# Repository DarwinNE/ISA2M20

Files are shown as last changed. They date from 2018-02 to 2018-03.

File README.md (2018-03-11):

# ISA2M20
Adapter for 8-bit ISA card for the Olivetti M20

This project is dedicated to an adapter that allows to connect 8 bit ISA boards to
the bus of an Olivetti M20. Yes, we are talking about 1982 technology.
That may allow to do some nice stuff on the M20 as long as you are able to write the
software for the cards you want to attach.

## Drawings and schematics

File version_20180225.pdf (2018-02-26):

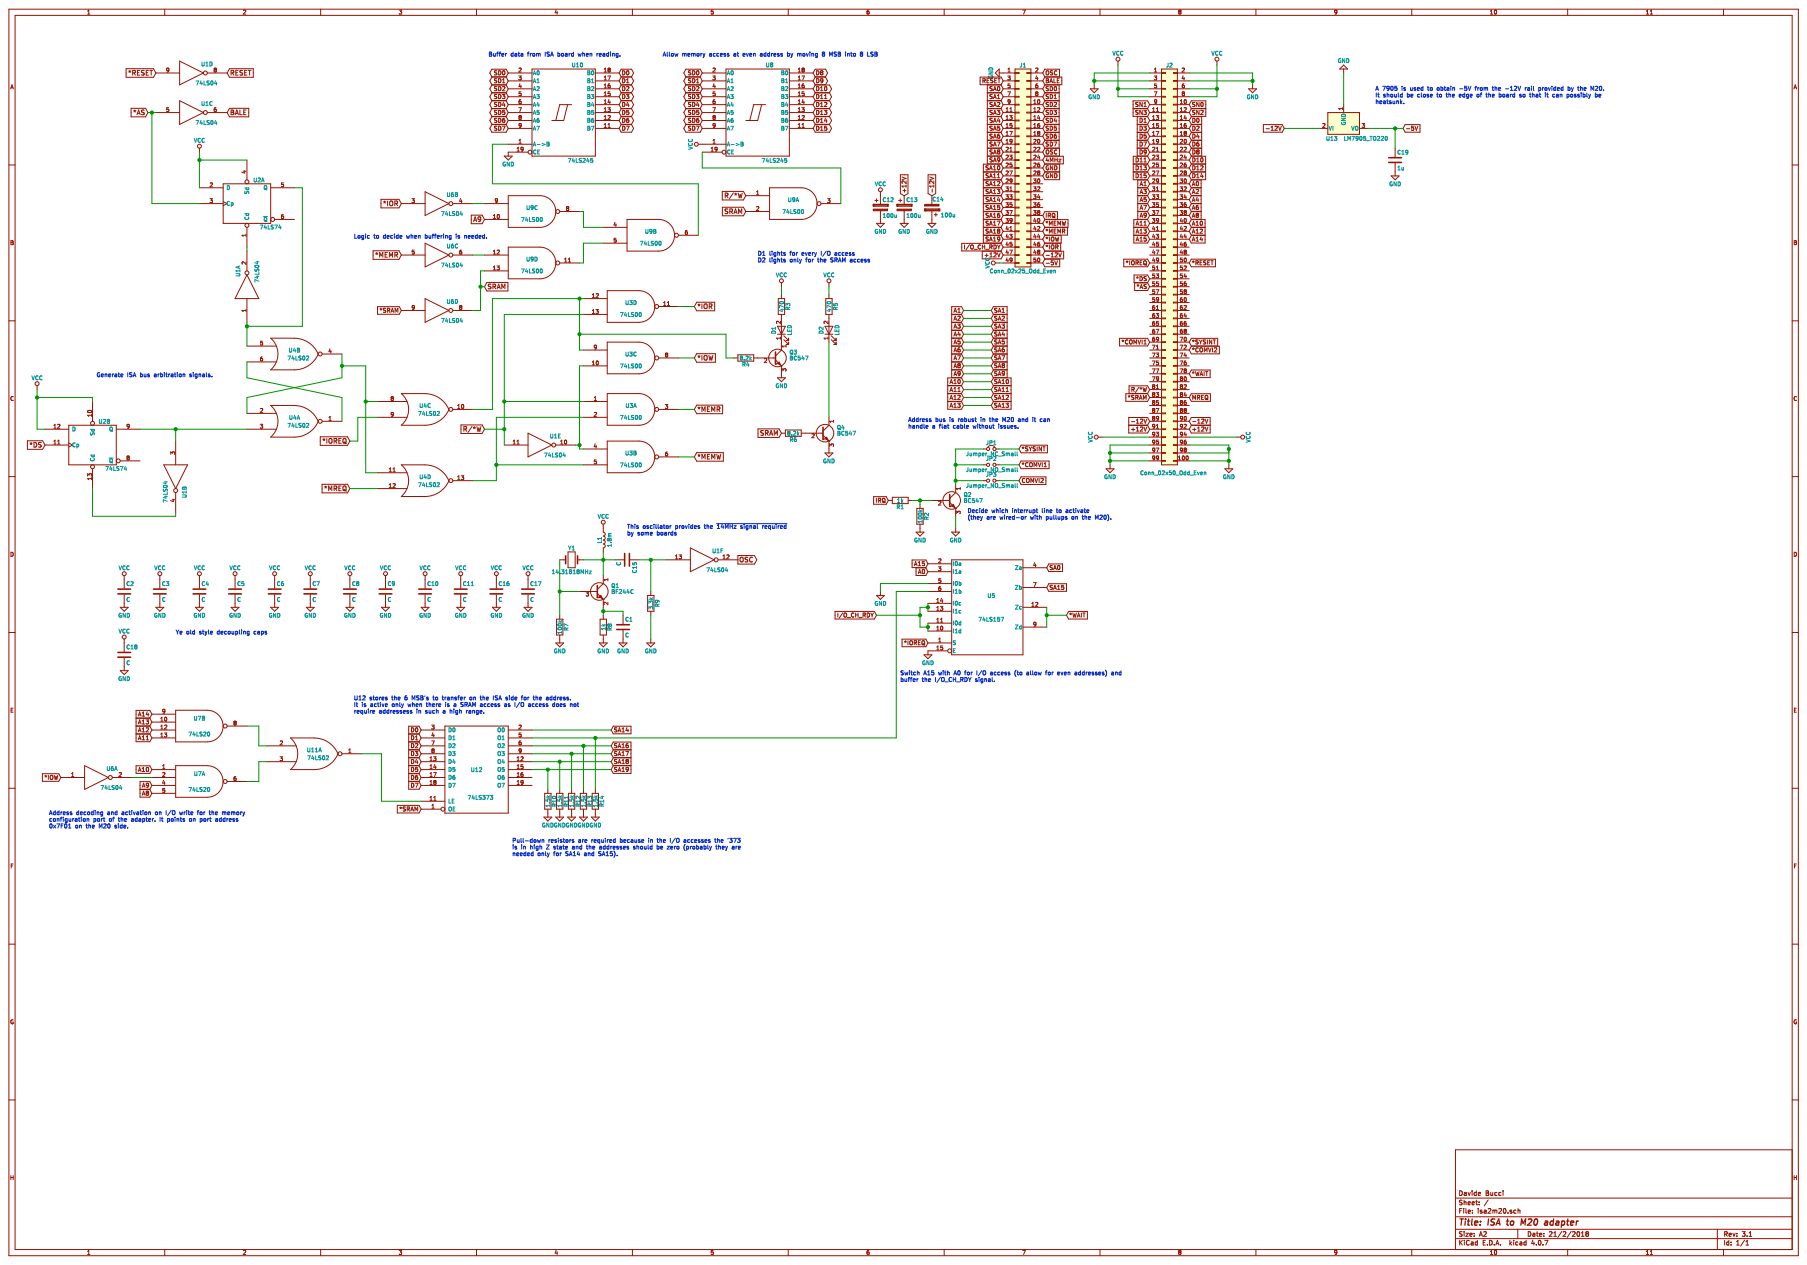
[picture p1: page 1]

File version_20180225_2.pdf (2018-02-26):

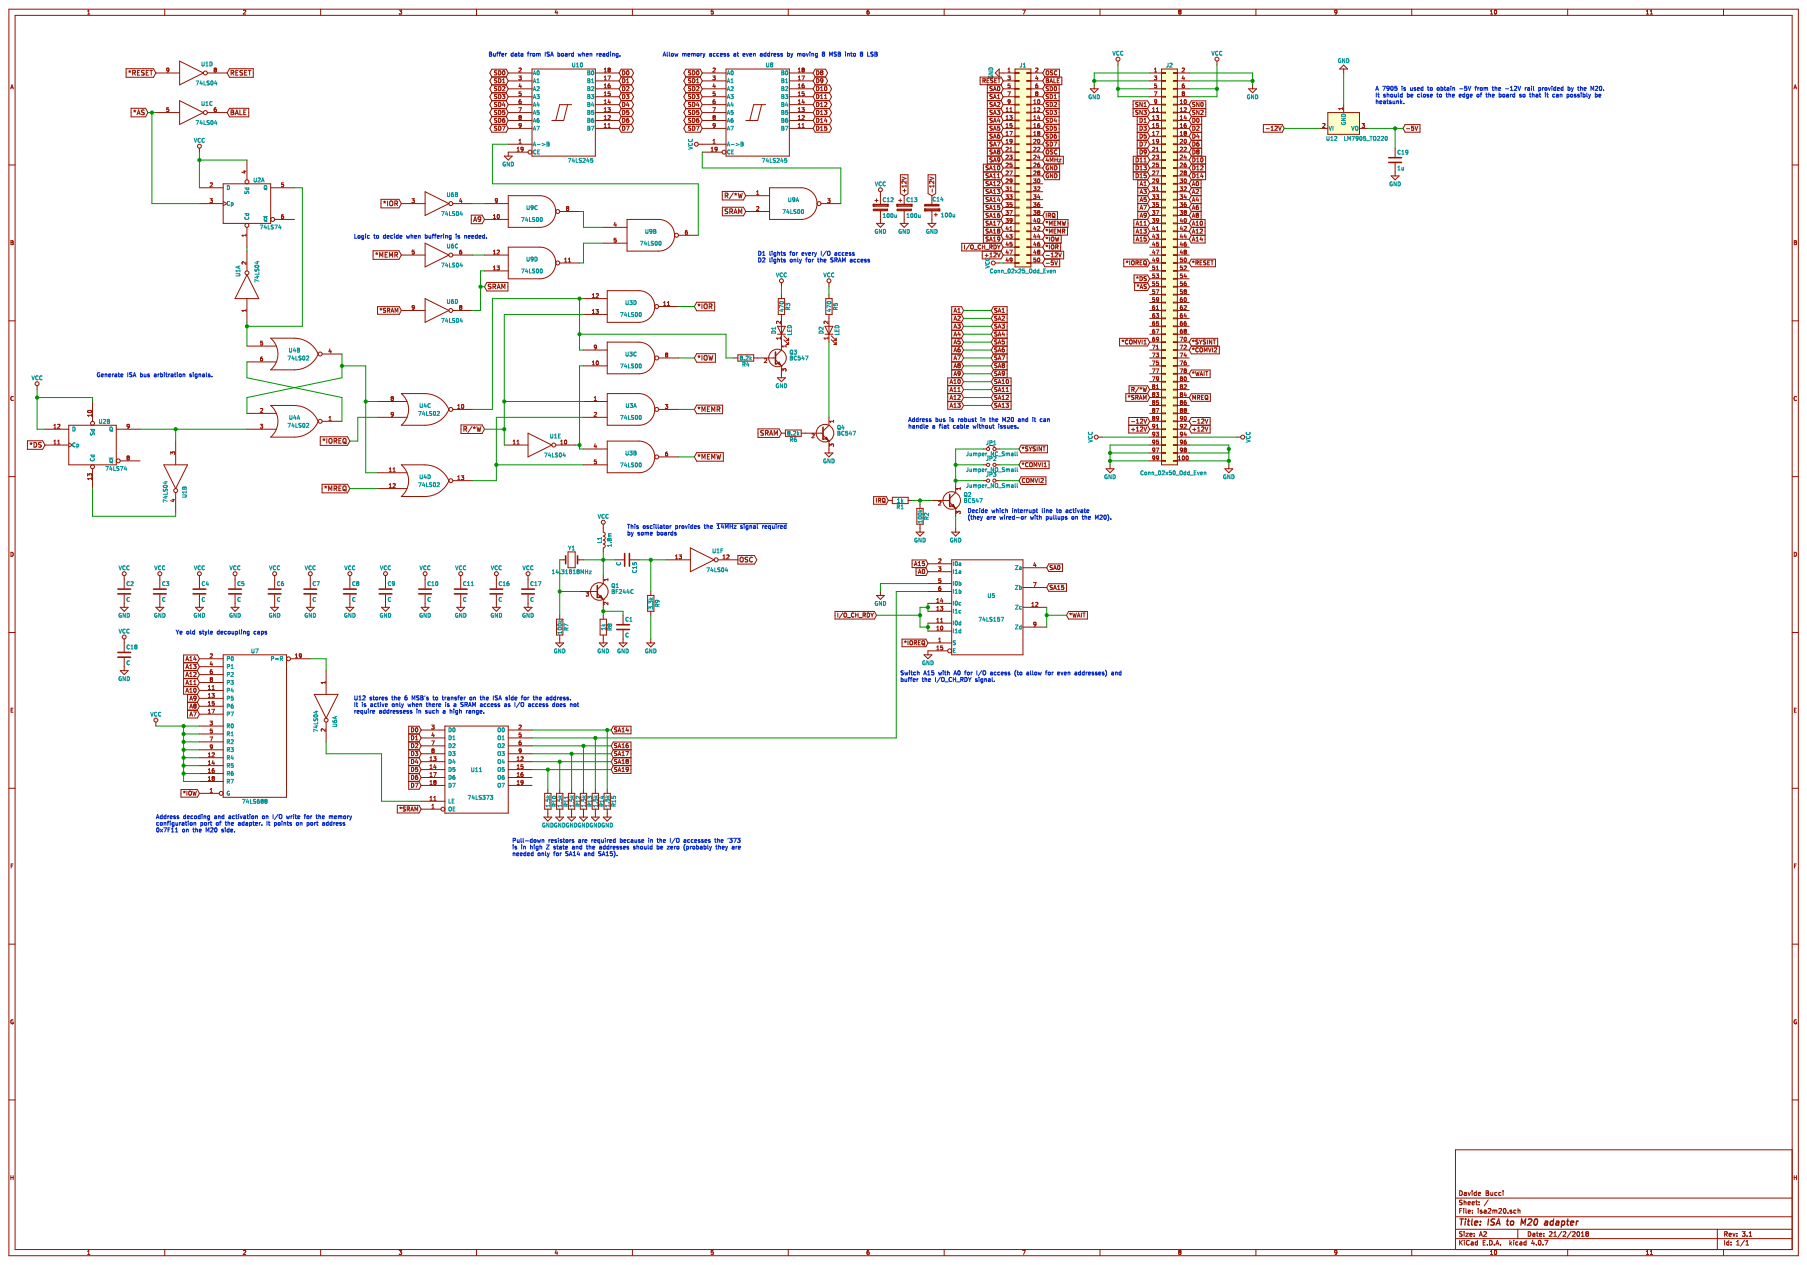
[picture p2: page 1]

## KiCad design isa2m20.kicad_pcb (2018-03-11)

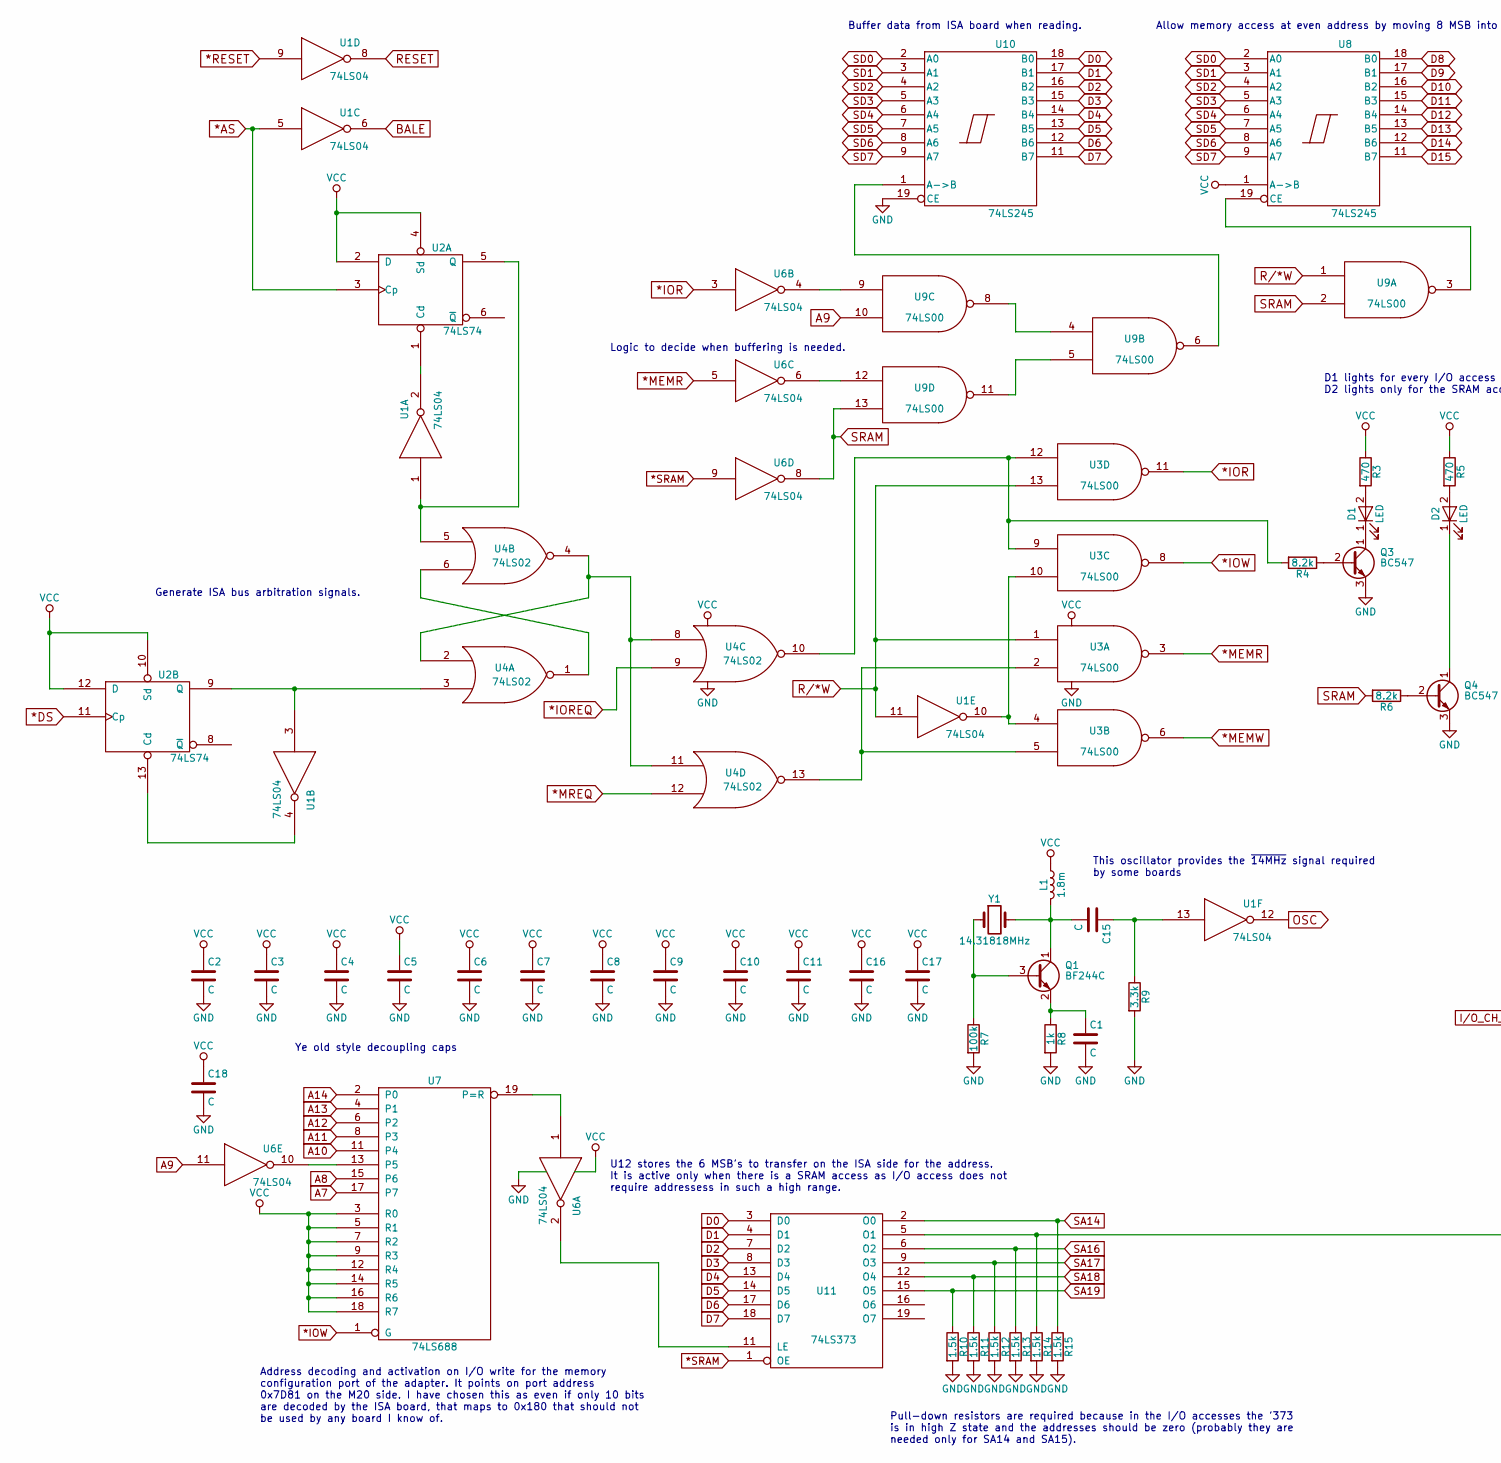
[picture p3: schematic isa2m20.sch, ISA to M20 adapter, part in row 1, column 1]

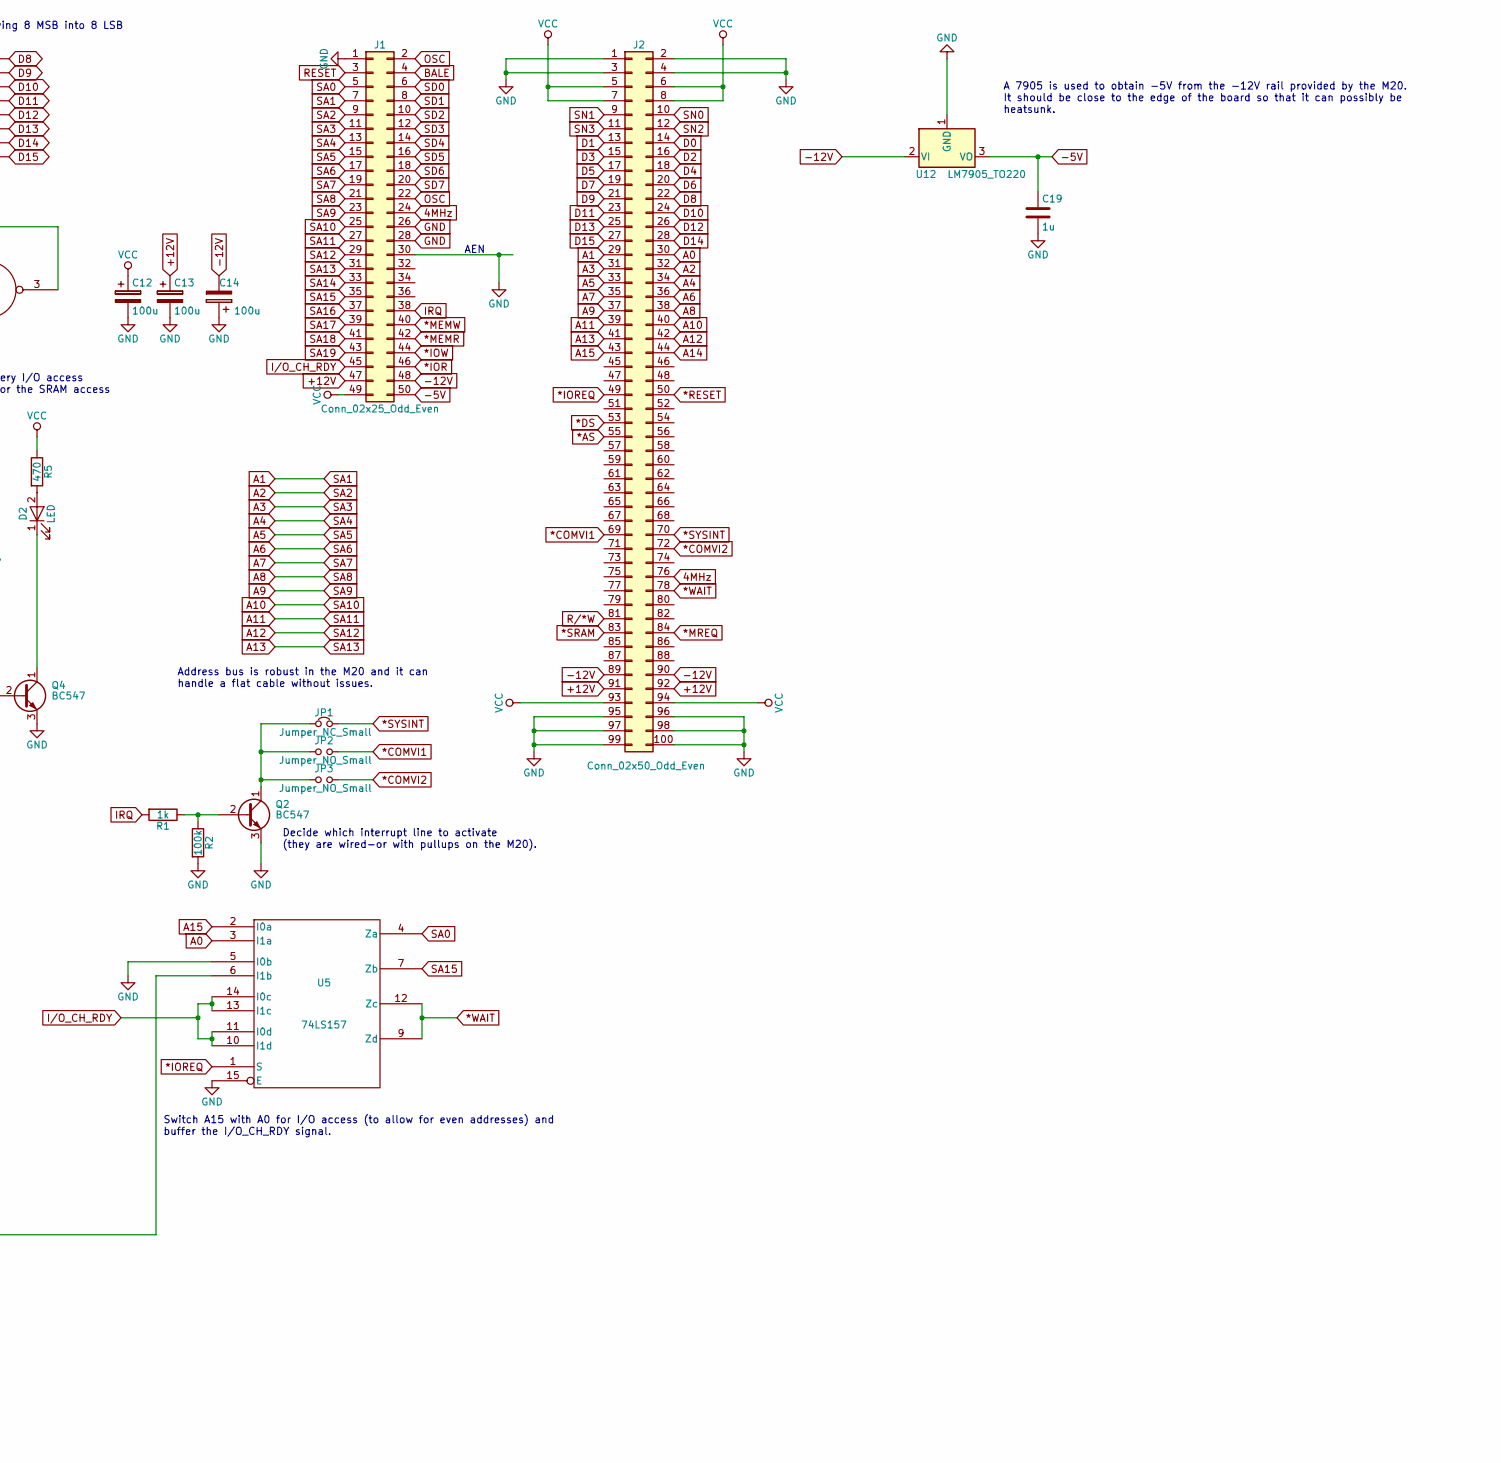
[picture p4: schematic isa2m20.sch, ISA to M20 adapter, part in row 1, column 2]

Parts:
C1: C; C_Axial_L5.1mm_D3.1mm_P7.50mm_Horizontal
C2, C3, C4, C5, C6, C7, C8, C9, C10, C11, C15, C16, C17, C18: C; C_Rect_L9.0mm_W2.5mm_P7.50mm_MKT
C12, C13, C14: 100u; CP_Radial_D10.0mm_P5.00mm
C19: 1u; C_Rect_L9.0mm_W2.5mm_P7.50mm_MKT
D1, D2: LED; LED_D3.0mm
J1: Conn_02x25_Odd_Even; Multicomp_MC9A12-5034_2x25x2.54mm_Straight
J2: Conn_02x50_Odd_Even; 2x50pin_PCB_edge_connector
JP1: Jumper_NC_Small; Socket_Strip_Straight_1x02_Pitch2.54mm
JP2, JP3: Jumper_NO_Small; Socket_Strip_Straight_1x02_Pitch2.54mm
L1: 1.8m; L_Radial_D7.5mm_P5.00mm_Fastron_07P
Q1: BF244C; TO-92_Molded_Narrow
Q2, Q3, Q4: BC547; TO-92_Molded_Narrow
R1, R8: 1k; R_Axial_DIN0207_L6.3mm_D2.5mm_P7.62mm_Horizontal
R2, R7: 100k; R_Axial_DIN0207_L6.3mm_D2.5mm_P7.62mm_Horizontal
R3, R5: 470; R_Axial_DIN0207_L6.3mm_D2.5mm_P7.62mm_Horizontal
R4, R6: 8.2k; R_Axial_DIN0207_L6.3mm_D2.5mm_P7.62mm_Horizontal
R9: 3.3k; R_Axial_DIN0207_L6.3mm_D2.5mm_P7.62mm_Horizontal
R10, R11, R12, R13, R14, R15: 1.5k; R_Axial_DIN0207_L6.3mm_D2.5mm_P7.62mm_Horizontal
U1, U6: 74LS04; DIP-14_W7.62mm_Socket_LongPads
U2: 74LS74; DIP-14_W7.62mm_Socket_LongPads
U3, U9: 74LS00; DIP-14_W7.62mm_Socket_LongPads
U4: 74LS02; DIP-14_W7.62mm_Socket_LongPads
U5: 74LS157; DIP-16_W7.62mm_Socket_LongPads
U7: 74LS688; DIP-20_W7.62mm_Socket_LongPads
U8, U10: 74LS245; DIP-20_W7.62mm_Socket_LongPads
U11: 74LS373; DIP-20_W7.62mm_Socket_LongPads
U12: LM7905_TO220; TO-220-3_Vertical
Y1: 14.31818MHz; Crystal_HC18-U_Vertical

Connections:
4MHz: J1.24, J2.76
*AS: J2.55, U1.5, U2.3 (Cp)
*COMVI1: J2.69, JP2.2
*COMVI2: J2.72, JP3.2
*DS: J2.53, U2.11 (Cp)
*IOR: J1.46, U3.11, U6.3
*IOREQ: J2.49, U4.9, U5.1 (S)
*IOW: J1.44, U3.8, U7.1 (G)
*MEMR: J1.42, U3.3, U6.5
*MEMW: J1.40, U3.6
*MREQ: J2.84, U4.12
*RESET: J2.50, U1.9
*SRAM: J2.83, U6.9, U11.1 (OE)
*SYSINT: J2.70, JP1.2
*WAIT: J2.78, U5.9 (Zd), U5.12 (Zc)
+12V: C13.1, J1.47, J2.91, J2.92
-5V: C19.1, J1.50, U12.3 (VO)
-12V: C14.2, J1.48, J2.89, J2.90, U12.2 (VI)
A0: J2.30, U5.3 (I1a)
A1: J1.7, J2.29
A2: J1.9, J2.32
A3: J1.11, J2.31
A4: J1.13, J2.34
A5: J1.15, J2.33
A6: J1.17, J2.36
A7: J1.19, J2.35, U7.17 (P7)
A8: J1.21, J2.38, U7.15 (P6)
A9: J1.23, J2.37, U6.11, U9.10
A10: J1.25, J2.40, U7.11 (P4)
A11: J1.27, J2.39, U7.8 (P3)
A12: J1.29, J2.42, U7.6 (P2)
A13: J1.31, J2.41, U7.4 (P1)
A14: J2.44, U7.2 (P0)
A15: J2.43, U5.2 (I0a)
BALE: J1.4, U1.6
D0: J2.14, U10.18 (B0), U11.3 (D0)
D1: J2.13, U10.17 (B1), U11.4 (D1)
D2: J2.16, U10.16 (B2), U11.7 (D2)
D3: J2.15, U10.15 (B3), U11.8 (D3)
D4: J2.18, U10.14 (B4), U11.13 (D4)
D5: J2.17, U10.13 (B5), U11.14 (D5)
D6: J2.20, U10.12 (B6), U11.17 (D6)
D7: J2.19, U10.11 (B7), U11.18 (D7)
D8: J2.22, U8.18 (B0)
D9: J2.21, U8.17 (B1)
D10: J2.24, U8.16 (B2)
D11: J2.23, U8.15 (B3)
D12: J2.26, U8.14 (B4)
D13: J2.25, U8.13 (B5)
D14: J2.28, U8.12 (B6)
D15: J2.27, U8.11 (B7)
GND: C1.2, C2.2, C3.2, C4.2, C5.2, C6.2, C7.2, C8.2, C9.2, C10.2, C11.2, C12.2, C13.2, C14.1, C16.2, C17.2, C18.2, C19.2, J1.1, J1.26, J1.28, J1.30, J2.1, J2.2, J2.3, J2.4, J2.95, J2.96, J2.97, J2.98, J2.99, J2.100, Q2.3 (E), Q3.3 (E), Q4.3 (E), R2.2, R7.2, R8.2, R9.2, R10.2, R11.2, R12.2, R13.2, R14.2, R15.2, U1.7 (GND), U2.7 (GND), U3.7 (GND), U4.7 (GND), U5.5 (I0b), U5.8 (GND), U5.15 (E), U6.7 (GND), U7.10 (GND), U8.10 (GND), U9.7 (GND), U10.10 (GND), U10.19 (CE), U11.10 (GND), U12.1 (GND)
I/O_CH_RDY: J1.45, U5.10 (I1d), U5.11 (I0d), U5.13 (I1c), U5.14 (I0c)
IRQ: J1.38, R1.2
unnamed: C1.1, Q1.2 (E), R8.1
unnamed: C15.1, R9.1, U1.13
unnamed: C15.2, L1.2, Q1.1 (C), Y1.2
unnamed: D1.1 (K), Q3.1 (C)
unnamed: D1.2 (A), R3.2
unnamed: D2.1 (K), Q4.1 (C)
unnamed: D2.2 (A), R5.2
unnamed: JP1.1, JP2.1, JP3.1, Q2.1 (C)
unnamed: Q1.3 (B), R7.1, Y1.1
unnamed: Q2.2 (B), R1.1, R2.1
unnamed: Q3.2 (B), R4.1
unnamed: Q4.2 (B), R6.1
unnamed: R4.2, U3.9, U3.12, U4.10
unnamed: R14.1, U5.6 (I1b), U11.5 (O1)
unnamed: U1.1, U2.5 (Q), U4.5
unnamed: U1.2, U2.1 (Cd)
unnamed: U1.3, U2.9 (Q), U4.3
unnamed: U1.4, U2.13 (Cd)
unnamed: U1.10, U3.4, U3.10
unnamed: U3.2, U3.5, U4.13
unnamed: U4.1, U4.6
unnamed: U4.2, U4.4, U4.8, U4.11
unnamed: U6.1, U7.19 (P=R)
unnamed: U6.4, U9.9
unnamed: U6.6, U9.12
unnamed: U6.10, U7.13 (P5)
unnamed: U8.19 (CE), U9.3
unnamed: U9.4, U9.8
unnamed: U9.5, U9.11
unnamed: U9.6, U10.1 (A->B)
unnamed: U6.2, U11.11 (LE)
OSC: J1.2, J1.22, U1.12
R/*W: J2.81, U1.11, U3.1, U3.13, U9.1
RESET: J1.3, U1.8
SA0: J1.5, U5.4 (Za)
SA14: J1.33, R15.1, U11.2 (O0)
SA15: J1.35, U5.7 (Zb)
SA16: J1.37, R13.1, U11.6 (O2)
SA17: J1.39, R12.1, U11.9 (O3)
SA18: J1.41, R11.1, U11.12 (O4)
SA19: J1.43, R10.1, U11.15 (O5)
SD0: J1.6, U8.2 (A0), U10.2 (A0)
SD1: J1.8, U8.3 (A1), U10.3 (A1)
SD2: J1.10, U8.4 (A2), U10.4 (A2)
SD3: J1.12, U8.5 (A3), U10.5 (A3)
SD4: J1.14, U8.6 (A4), U10.6 (A4)
SD5: J1.16, U8.7 (A5), U10.7 (A5)
SD6: J1.18, U8.8 (A6), U10.8 (A6)
SD7: J1.20, U8.9 (A7), U10.9 (A7)
SN0: J2.10
SN1: J2.9
SN2: J2.12
SN3: J2.11
SRAM: R6.2, U6.8, U9.2, U9.13
VCC: C2.1, C3.1, C4.1, C5.1, C6.1, C7.1, C8.1, C9.1, C10.1, C11.1, C12.1, C16.1, C17.1, C18.1, J1.49, J2.5, J2.6, J2.7, J2.8, J2.93, J2.94, L1.1, R3.1, R5.1, U1.14 (VCC), U2.2 (D), U2.4 (Sd), U2.10 (Sd), U2.12 (D), U2.14 (VCC), U3.14 (VCC), U4.14 (VCC), U5.16 (VCC), U6.14 (VCC), U7.3 (R0), U7.5 (R1), U7.7 (R2), U7.9 (R3), U7.12 (R4), U7.14 (R5), U7.16 (R6), U7.18 (R7), U7.20 (VCC), U8.1 (A->B), U8.20 (VCC), U9.14 (VCC), U10.20 (VCC), U11.20 (VCC)

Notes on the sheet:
A 7905 is used to obtain -5V from the -12V rail provided by the M20. It should be close to the edge of the board so that it can possibly be heatsunk.
This oscillator provides the ~14MHz signal required by some boards
D1 lights for every I/O access D2 lights only for the SRAM access
U12 stores the 6 MSB's to transfer on the ISA side for the address. It is active only when there is a SRAM access as I/O access does not require addressess in such a high range.
Address decoding and activation on I/O write for the memory configuration port of the adapter. It points on port address 0x7D81 on the M20 side. I have chosen this as even if only 10 bits are decoded by the ISA board, that maps to 0x180 that should not be used by any board I know of.
Pull-down resistors are required because in the I/O accesses the '373 is in high Z state and the addresses should be zero (probably they are needed only for SA14 and SA15).
Ye old style decoupling caps
Allow memory access at even address by moving 8 MSB into 8 LSB
Buffer data from ISA board when reading.
Logic to decide when buffering is needed.
Generate ISA bus arbitration signals.
Address bus is robust in the M20 and it can handle a flat cable without issues.
Decide which interrupt line to activate (they are wired-or with pullups on the M20).
Switch A15 with A0 for I/O access (to allow for even addresses) and buffer the I/O_CH_RDY signal.
AEN

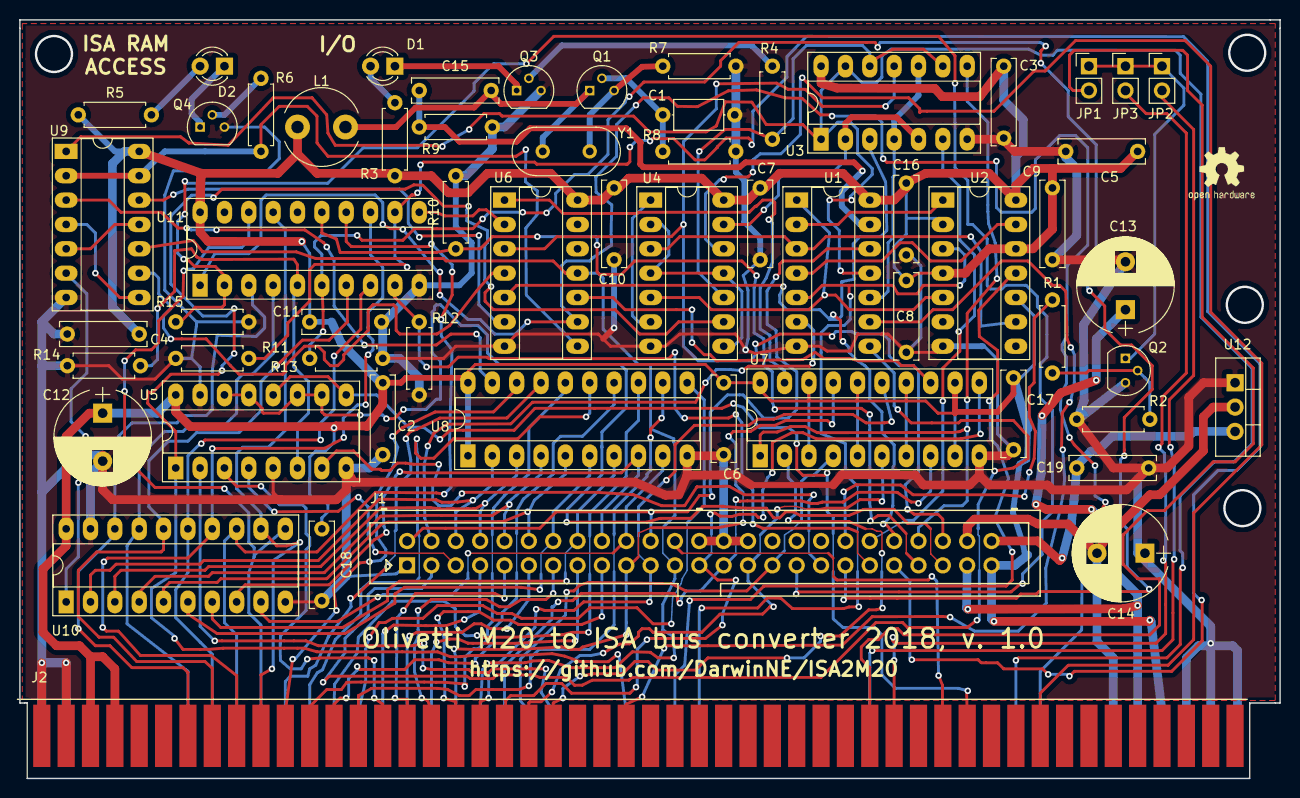
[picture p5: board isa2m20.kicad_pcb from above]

Board: 2 copper layers, 131.4 x 79.1 mm, 59 parts (0 on the bottom side), 105 nets.

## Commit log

2018-02-26 First version of the ISA2M20 adapter, still to route.
    [PCB_manifacturing.xlsx, _saved_isa2m20.sch, isa2m20.kicad_pcb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]
2018-02-26 A little cleanup.
    [PCB_manifacturing.xlsx]
2018-02-26 Modify the configuration I/O address so to avoid potential conflicts with boards decoding only 10 bits on the ISA side.
    [_saved_isa2m20.sch, isa2m20.sch]
2018-02-26 Started routing power rails.
    [isa2m20.kicad_pcb, isa2m20.sch]
2018-02-27 Continue routing.
    [isa2m20.kicad_pcb]
2018-02-27 The most difficult part remains to be done.
    [isa2m20.kicad_pcb]
2018-03-01 Continued routing. Quite difficult stage now...
    [isa2m20.kicad_pcb]
2018-03-05 Continue routing. Quite difficult paths here.
    [isa2m20.kicad_pcb]
2018-03-05 Routing continues as hard as it gets.
    [isa2m20.kicad_pcb]
2018-03-06 7 connections remaining, but they are the though ones...
    [isa2m20.kicad_pcb]
2018-03-06 4 more connections to route.
    [isa2m20.kicad_pcb]
2018-03-08 Two connections to route.
    [isa2m20.kicad_pcb]
2018-03-08 Board 100% routed. I still add to beautify the connections and to improve some ugly stuff. There is still some ERC violation to address.
    [isa2m20.kicad_pcb]
2018-03-10 Beutified a little the card, but still a lot of work remains to be done.
    [isa2m20.kicad_pcb, isa2m20.sch]
2018-03-11 Tweaked some details.
    [isa2m20.kicad_pcb]
2018-03-11 Continue to beautify.
    [isa2m20.kicad_pcb]
